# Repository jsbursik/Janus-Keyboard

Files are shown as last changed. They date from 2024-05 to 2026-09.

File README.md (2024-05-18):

# Janus Split Ergonomic Keyboard

## Janus

From [Wikipedia](https://en.wikipedia.org/wiki/Janus) on the god Janus: "In ancient Roman religion and myth, Janus (/ˈdʒeɪnəs/ JAY-nəs; Latin: Ianvs [ˈi̯aːnʊs]) is the god of beginnings, gates, transitions, time, duality, doorways, passages, frames, and endings. He is usually depicted as having two faces. The month of January is named for Janus (Ianuarius). According to ancient Roman farmers' almanacs, Juno was mistaken as the tutelary deity of the month of January, but Juno is the tutelary deity of the month of June."

## Motivation

I designed this keyboard after ordering and assembling a [Piantor](https://github.com/beekeeb/piantor) and not really liking the switches and keycaps. After realizing choc switches don't use the normal "+" stems I'm used to and seeing that the choc stems are a bit niche for finding keycaps - I started looking for other low-profile switch options that supported the more ubiquitous "+" stems.

Other issues involved key density, I didn't like how close together everything was. I stretched my fingers out, then closed them up and tried to get a shape that roughly followed the paths of my fingertips. I also added a few more keys than the Piantor has making this a 50 key (25 x 2) keyboard.

In comes the KS27 from Gateron. At one point I had owned a wireless keyboard that used the KS27 Linear Red switches and liked them for the most part, but these days I prefer a more tactile switch (break-over feel without the click). After finding some KS27 Browns on Amazon, I concluded they were what I was looking for. I found the hotswap sockets for the KS27 on Aliexpress and ordered a few hundred to be safe since shipping times were so long. Next I was on the hunt for blank keycaps and found that it was pretty easy to source some blank DSA profile caps from Amazon as well. I haven't used them on a full keyboard yet, but I believe it should be easier to feel out the different keys than the choc low-profile keycaps that came with the Piantor.

## Workflow

I used the web version of Ergogen [here](https://ergogen.cache.works) to get the general shape down until I was ready for all the footprinting and stuff that would have to happen locally. Once I was happy with the general shape, I went through the tedious task of editing footprints and converting them to the `.js` versions that Ergogen expects in the `footprints/` folder. I set up [npm-watch](https://www.npmjs.com/package/npm-watch) (`npm run watch`) to watch out for changes to the `config.yaml` file to automatically run Ergogen. Once everything was placed where I wanted it, I created a `kicad_project` folder separate from the output folder so any Ergogen runs down the road won't effect my work in Kicad (`npm run pcb-update` moves new PCB changes to the `kicad_project` folder). I then routed everything in KiCad version 8, making sure to weave the traces for the reversible nice!nano v2 footprint I made. After everything was routed and the DRC reported no errors, I exported the gerbers and sent them off to JLCPCB. The case was also generated using Ergogen as it's easy enough to do, still working on tweaking some clearances to make everything fit nicely.

## ZMK

This keyboard is meant to use the [nice!nano v2](https://nicekeyboards.com/nice-nano) with the [nice!view screen](https://nicekeyboards.com/nice-view) which means my firmware options were limited as this will be full wireless. The obvious choice feature-wise is ZMK. The documentation is a bit rough around the edges so I've had to do a decent amount of trial and error, as well as researching other ergo keyboard repos to see what they did. The firmware repo for this version of the Janus can be found [here](https://github.com/jsbursik/zmk-janus).

## Parts

| Part | Quantity |
| --- | --- |
| nice!nano v2 | 2 |
| sockets/pins for n!n v2 | 2 sets |
| nice!view | 2 |
| 5 pin header for nice!view, should come with it | 2 sets |
| 3.7v Lithium Battery | 2 |
| Gateron KS27 Hotswap Sockets | 50 |
| Gateron KS27 Low profile Switches | 50 |
| 1N4148 Diodes (SMD or Thru-hole) | 100 |
| M2 \* 4mm screws | 14 |
| M2 Threaded inserts 2 x 3 x 3.5mm | 14 |

Other than that, you just need the PCBs and keycaps of your choice.

Links to where I bought my parts:

- [nice!nano v2](https://typeractive.xyz/products/nice-nano)
- [nice!view](https://typeractive.xyz/products/nice-view)
- [sockets/pins](https://typeractive.xyz/products/machine-sockets-and-pins)
- [lithium batteries](https://typeractive.xyz/products/lithium-battery-110mah)
- [Gateron low-profile hot-swap socket](https://www.gateron.com/products/gateron-low-profile-switch-hot-swap-pcb-socket?VariantsId=10234)
- [Gateron KS27 brown switched](https://www.amazon.com/Gateron-ks-27-Switches-Mechanical-Keyboards/dp/B09WYGKDVN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)
- [1N4148WS Surface Mount Diodes x100](https://www.amazon.com/dp/B089KD46P6?psc=1&ref=ppx_yo2ov_dt_b_product_details)
- [M2 screws](https://www.amazon.com/dp/B0BX96SMW4?psc=1&ref=ppx_yo2ov_dt_b_product_details)
- [M2 threaded inserts](https://www.amazon.com/dp/B0B8GN63S2?psc=1&ref=ppx_yo2ov_dt_b_product_details)

## Keymap Layout

This is still very much a work in progress. I've been using the [keymap editor found here](https://nickcoutsos.github.io/keymap-editor/) to try and come up with a barebones setup.

** TODO: add images

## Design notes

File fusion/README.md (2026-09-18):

# Fusion case script

`JanusCase` rebuilds the ergogen case as a native Fusion design instead of an STL:
real sketches (lines, arcs, circles) and extrudes, with every height as a user parameter.

## Use

1. Run `npm run build` so `output/outlines` contains the ergogen outline DXFs (including the `_`-prefixed debug ones).
2. In Fusion: **Utilities → Add-Ins → Scripts and Add-Ins**, click **+** next to *My Scripts*, choose *Script or add-in from device*, and pick the `fusion/JanusCase` folder.
3. Select **JanusCase** and click **Run**. It opens a new design with:
   - **Case left**: floor + wall − slider cutout + insert standoffs + PCB supports, as in the `case` recipe in `config.yaml`
   - **Case right**: a mirror of the left half
   - **PCB outline** sketch at the height the PCB sits, and a hidden **Keycaps** sketch
4. Change heights under **Modify → Change Parameters** (`floor_thickness`, `wall_height`, `standoff_height`, ...).

Outline shapes (wall thickness, clearance, insert positions) still come from `config.yaml`.
Change them there, rebuild, and run the script again.

The script expects Fusion's default **Z up** orientation. With Y up, the case is built standing on its edge.

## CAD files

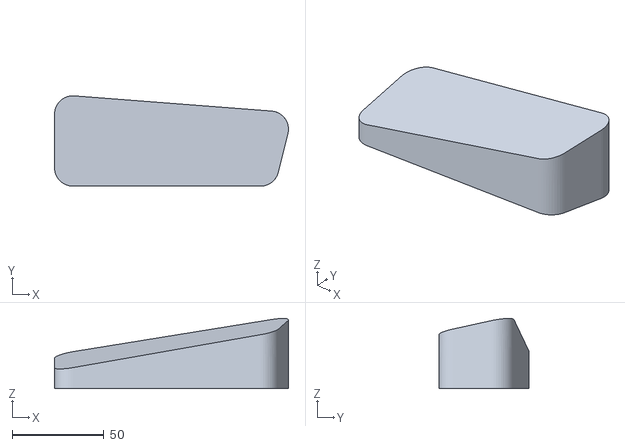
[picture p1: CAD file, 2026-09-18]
output/cases/Split Keyboard Support LH.stl
127.4 x 49.2 x 38.2

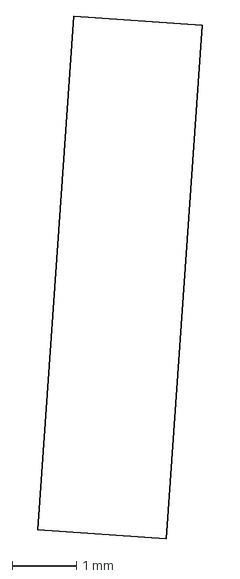
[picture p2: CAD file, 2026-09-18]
output/outlines/_slider_hole.dxf
2.55 x 8.12 mm

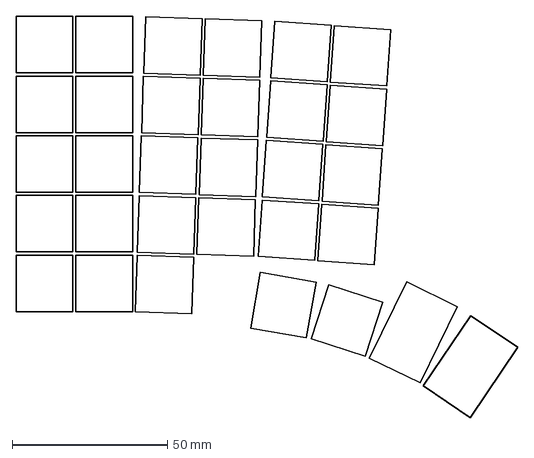
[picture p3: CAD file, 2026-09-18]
output/points/demo.dxf
161.4 x 129.1 mm

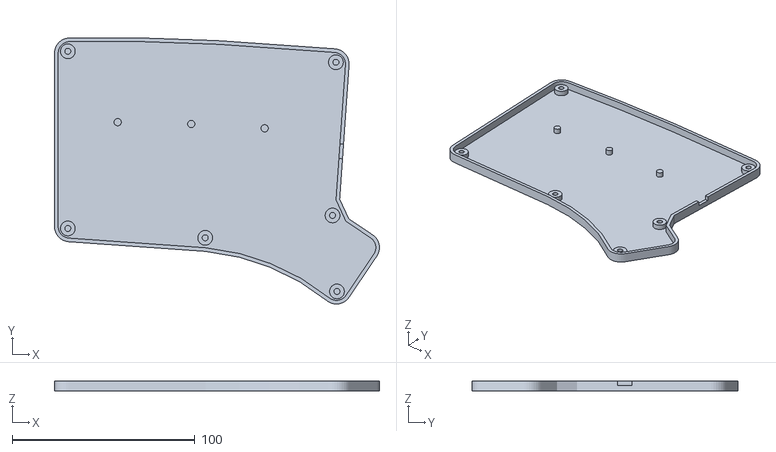
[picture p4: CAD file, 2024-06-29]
output/cases/case.stl
178.0 x 145.7 x 5.60

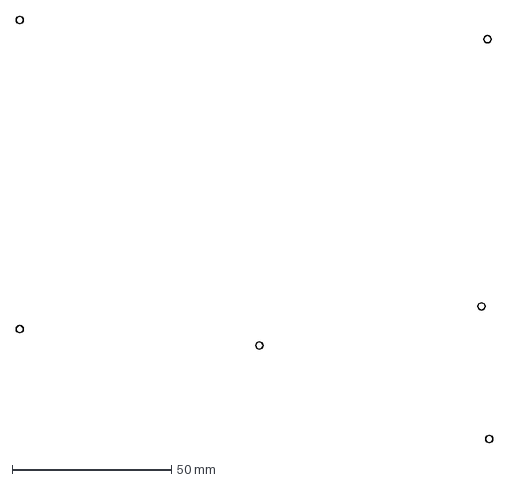
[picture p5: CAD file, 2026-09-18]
output/outlines/_board_holes.dxf
149.7 x 133.8 mm

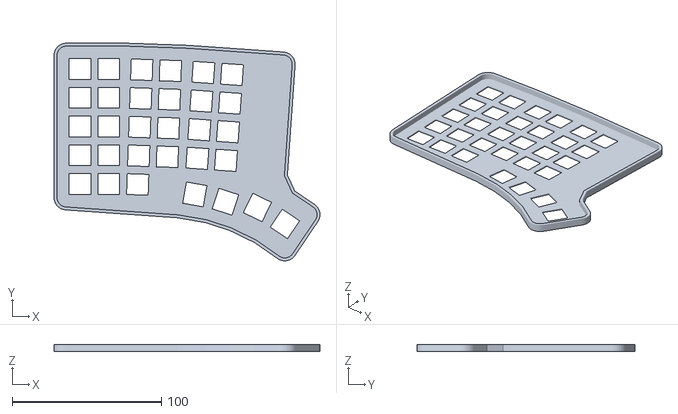
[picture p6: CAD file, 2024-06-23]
output/cases/key_tester.stl
178.0 x 145.7 x 5.00

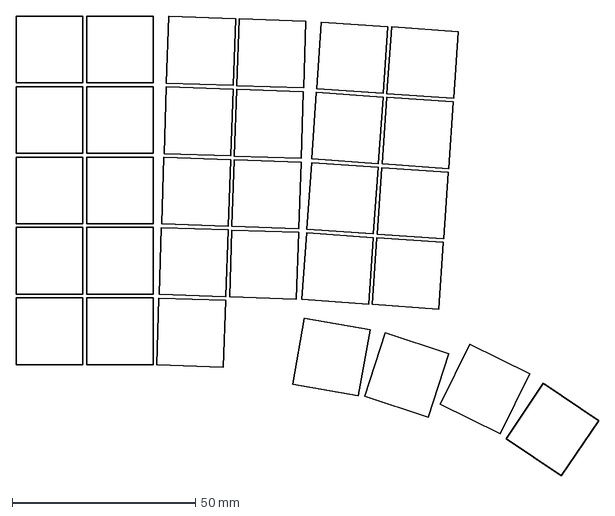
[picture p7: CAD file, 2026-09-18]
output/outlines/keycaps.dxf
158.8 x 125.3 mm

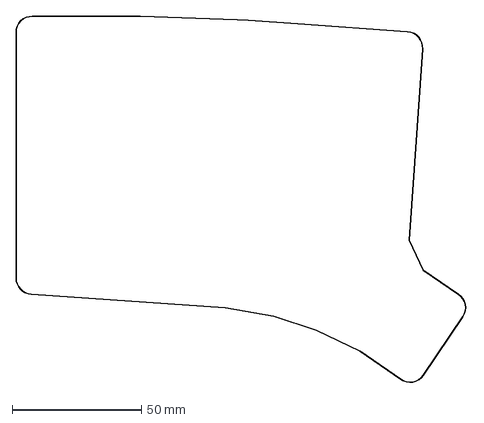
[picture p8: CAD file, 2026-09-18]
output/outlines/_board_case_clearance.dxf
174.8 x 141.9 mm

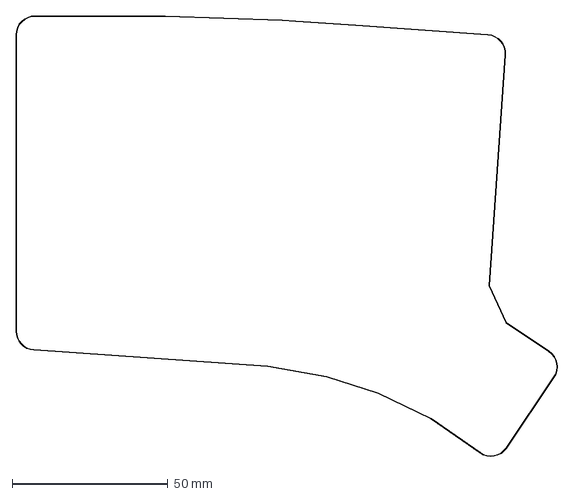
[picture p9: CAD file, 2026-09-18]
output/outlines/board.dxf
174.2 x 141.3 mm

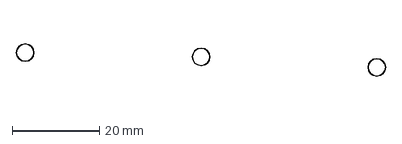
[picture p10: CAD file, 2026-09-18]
output/outlines/_board_supports.dxf
84.5 x 7.36 mm

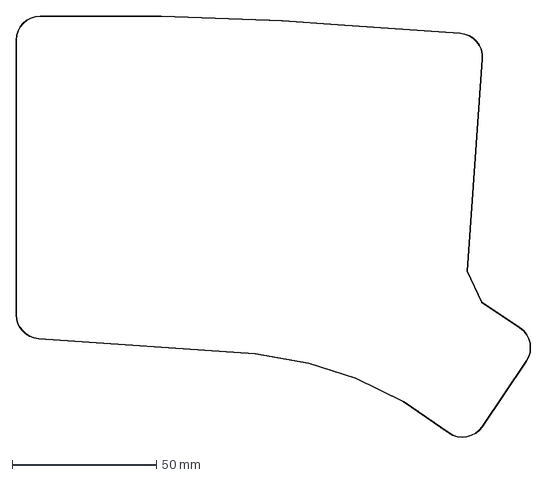
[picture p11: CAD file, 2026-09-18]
output/outlines/_board_xl.dxf
179.1 x 146.0 mm

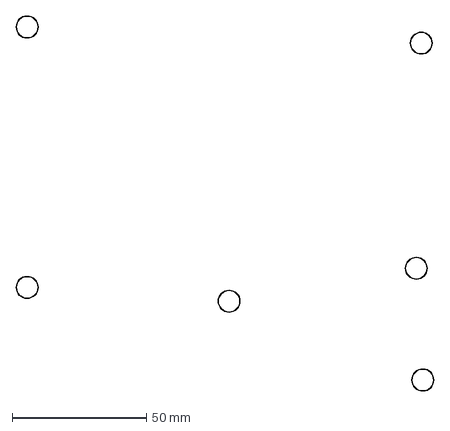
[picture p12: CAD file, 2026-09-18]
output/outlines/_insert_walls.dxf
155.5 x 139.6 mm

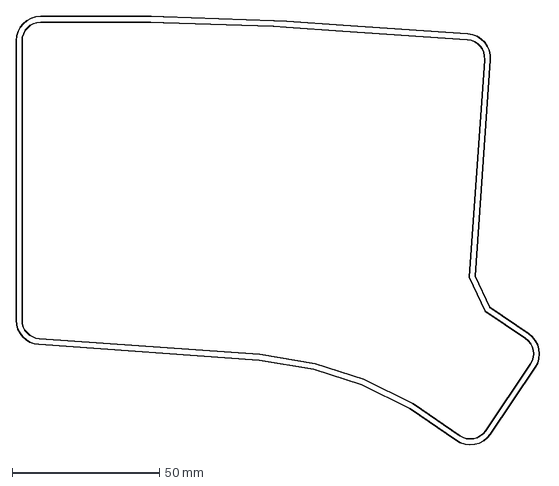
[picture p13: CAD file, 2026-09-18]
output/outlines/wall.dxf
179.1 x 146.0 mm

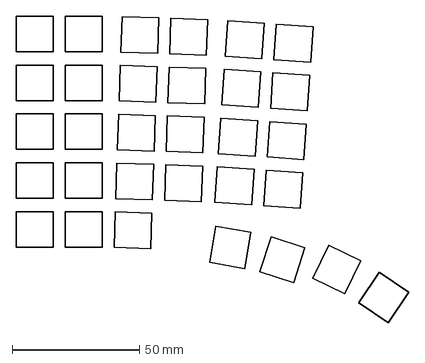
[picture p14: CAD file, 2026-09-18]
output/outlines/switches.dxf
154.1 x 120.5 mm

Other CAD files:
output/outlines/_insert_holes.dxf
output/outlines/inserts.dxf
output/outlines/keyplate.dxf
output/outlines/drilled_board.dxf
output/outlines/board_xl.dxf
output/outlines/combo.dxf
output/outlines/holes.dxf
output/outlines/keyplate_drilled.dxf
output/outlines/standoffs.dxf

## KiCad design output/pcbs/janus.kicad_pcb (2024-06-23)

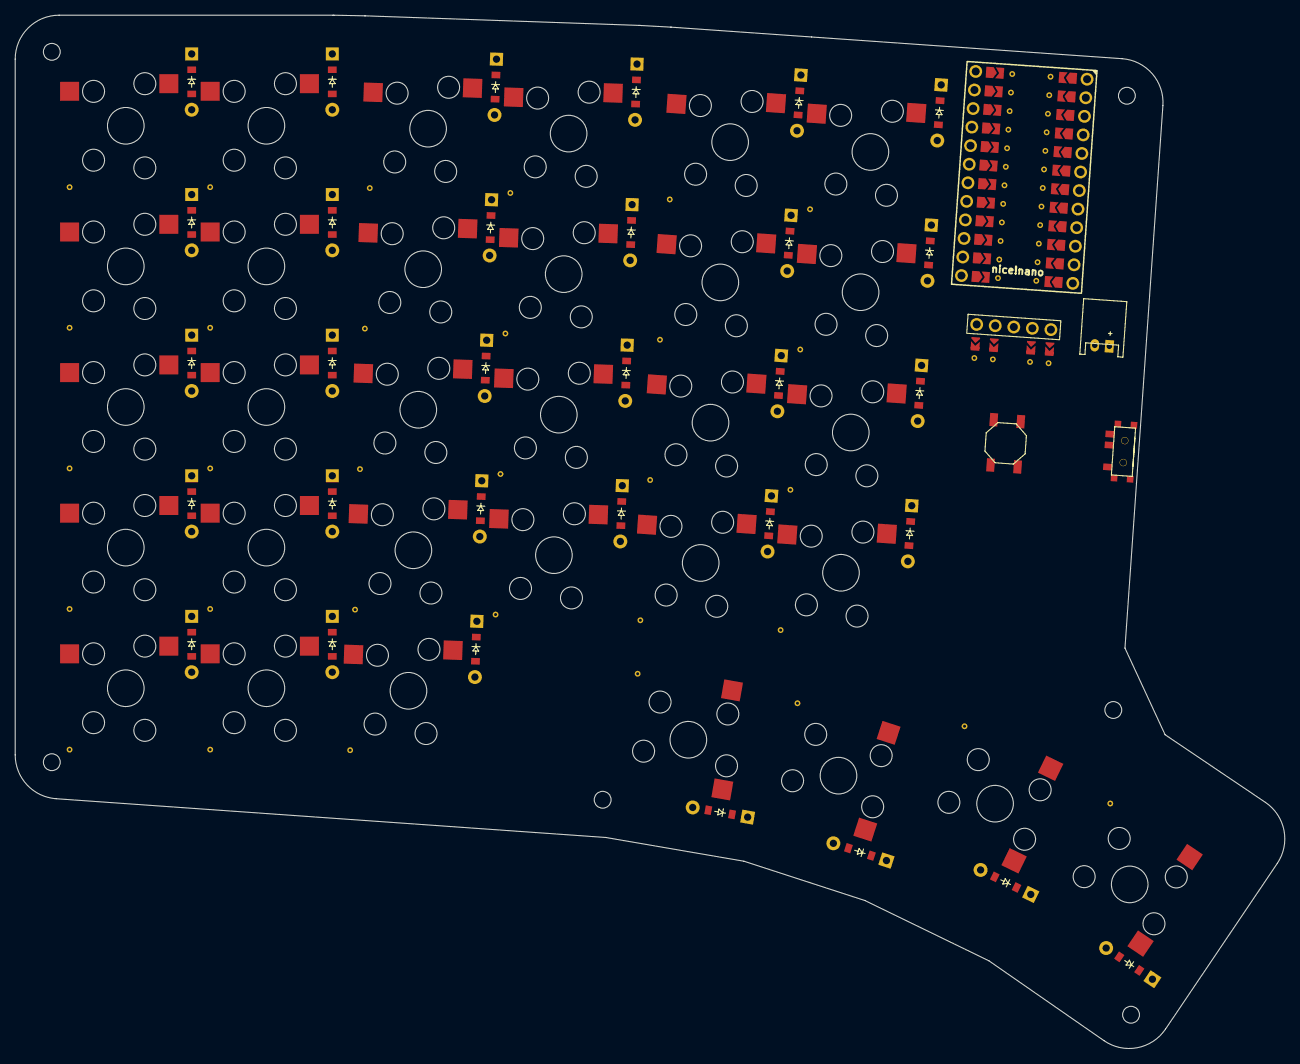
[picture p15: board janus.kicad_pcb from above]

Board: 2 copper layers, 173.4 x 141.1 mm, 67 parts (0 on the bottom side), 48 nets, no tracks yet.

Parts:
B1: SW_TACT_ALPS_SKQGABE010
D1, D2, D3, D4, D5, D6, D7, D8, D9, D10, D11, D12, D13, D14, D15, D16, D17, D18, D19, D20, D21, D22, D23, D24, D25, D26, D27, D28, D29, D30, D31: ComboDiode
JST1: JST_PH_S2B-PH-K_02x2.00mm_Angled
MCU1: nice!nano_v2
OLED1: nice!view; niceview
S1, S2, S3, S4, S5, S6, S7, S8, S9, S10, S11, S12, S13, S14, S15, S16, S17, S18, S19, S20, S21, S22, S23, S24, S25, S26, S27, S28, S29, S30, S31: ks27; gateron-ks27
T1: SPDT_C128955

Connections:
BPOS: JST1.1, T1.1
GND: B1.1, JST1.2, MCU1.GND
P5: D5.1, D10.1, D15.1, D19.1, D23.1, D27.1, MCU1.P5
P6: D4.1, D9.1, D14.1, D18.1, D22.1, D26.1, MCU1.P6
P7: D3.1, D8.1, D13.1, D17.1, D21.1, D25.1, MCU1.P7
P8: D2.1, D7.1, D12.1, D16.1, D20.1, D24.1, MCU1.P8
P9: D1.1, D6.1, D11.1, D28.1, D29.1, D30.1, D31.1, MCU1.P9
P10: MCU1.P10, S16.1, S17.1, S18.1, S19.1, S28.1
P14: MCU1.P14, S6.1, S7.1, S8.1, S9.1, S10.1
P15: MCU1.P15, S1.1, S2.1, S3.1, S4.1, S5.1
P16: MCU1.P16, S11.1, S12.1, S13.1, S14.1, S15.1
P18: MCU1.P18, S31.1
P19: MCU1.P19, S20.1, S21.1, S22.1, S23.1, S29.1
P20: MCU1.P20, S24.1, S25.1, S26.1, S27.1, S30.1
RAW: MCU1.B+, T1.2
RST: B1.2, MCU1.RST
VCC: MCU1.VCC, OLED1.3
home_cluster: D30.2, S30.2
index_bottom: D20.2, S20.2
index_home: D21.2, S21.2
index_number: D23.2, S23.2
index_top: D22.2, S22.2
inner_bottom: D24.2, S24.2
inner_cluster: D29.2, S29.2
inner_home: D25.2, S25.2
inner_number: D27.2, S27.2
inner_top: D26.2, S26.2
middle_bottom: D16.2, S16.2
middle_home: D17.2, S17.2
middle_number: D19.2, S19.2
middle_top: D18.2, S18.2
mod_cluster: D28.2, S28.2
outer_bottom: D2.2, S2.2
outer_cluster: D31.2, S31.2
outer_home: D3.2, S3.2
outer_mod: D1.2, S1.2
outer_number: D5.2, S5.2
outer_top: D4.2, S4.2
pinky_bottom: D7.2, S7.2
pinky_home: D8.2, S8.2
pinky_mod: D6.2, S6.2
pinky_number: D10.2, S10.2
pinky_top: D9.2, S9.2
ring_bottom: D12.2, S12.2
ring_home: D13.2, S13.2
ring_mod: D11.2, S11.2
ring_number: D15.2, S15.2
ring_top: D14.2, S14.2

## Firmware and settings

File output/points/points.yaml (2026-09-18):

matrix_outer_mod:
    x: 50
    'y': -150
    r: 0
    meta:
        stagger: 0
        spread: 19.2
        splay: 0
        origin:
            - 0
            - 0
        orient: 0
        shift:
            - 0
            - 0
        rotate: 0
        adjust: {}
        width: 18.2
        height: 18.2
        padding: 19.2
        autobind: 10
        skip: false
        asym: both
        colrow: outer_mod
        name: matrix_outer_mod
        column_net: P15
        row_net: P9
        zone:
            columns:
                outer:
                    key:
                        column_net: P15
                    rows: {}
                    name: outer
                pinky:
                    key:
                        column_net: P14
                    rows: {}
                    name: pinky
                ring:
                    key:
                        splay: -2
                        spread: kp + 0.2
                        stagger: -0.35
                        column_net: P16
                    rows: {}
                    name: ring
                middle:
                    rows:
                        mod:
                            skip: true
                    key:
                        column_net: P10
                    name: middle
                index:
                    key:
                        splay: -2
                        spread: kp + 0.2
                        stagger: -0.35
                        column_net: P19
                    rows:
                        mod:
                            skip: true
                    name: index
                inner:
                    rows:
                        mod:
                            skip: true
                    key:
                        column_net: P20
                    name: inner
            rows:
                mod:
                    row_net: P9
                bottom:
                    row_net: P8
                home:
                    row_net: P7
                top:
                    row_net: P6
                number:
                    row_net: P5
            name: matrix
        col:
            key:
                column_net: P15
            rows: {}
            name: outer
        row: mod
        bind:
            - 10
            - 10
            - 0
            - 0
matrix_outer_bottom:
    x: 50
    'y': -130.8
    r: 0
    meta:
        stagger: 0
        spread: 19.2
        splay: 0
        origin:
            - 0
            - 0
        orient: 0
        shift:
            - 0
            - 0
        rotate: 0
        adjust: {}
        width: 18.2
        height: 18.2
        padding: 19.2
        autobind: 10
        skip: false
        asym: both
        colrow: outer_bottom
        name: matrix_outer_bottom
        column_net: P15
        row_net: P8
        zone:
            columns:
                outer:
                    key:
                        column_net: P15
                    rows: {}
                    name: outer
                pinky:
                    key:
                        column_net: P14
                    rows: {}
                    name: pinky
                ring:
                    key:
                        splay: -2
                        spread: kp + 0.2
                        stagger: -0.35
                        column_net: P16
                    rows: {}
                    name: ring
                middle:
                    rows:
                        mod:
                            skip: true
                    key:
                        column_net: P10
                    name: middle
                index:
                    key:
                        splay: -2
                        spread: kp + 0.2
                        stagger: -0.35
                        column_net: P19
                    rows:
                        mod:
                            skip: true
                    name: index
                inner:
                    rows:
                        mod:
                            skip: true
                    key:
                        column_net: P20
                    name: inner
            rows:
                mod:
                    row_net: P9
                bottom:
                    row_net: P8
                home:
                    row_net: P7
                top:
                    row_net: P6
                number:
                    row_net: P5
            name: matrix
        col:
            key:
                column_net: P15
            rows: {}
            name: outer
        row: bottom
        bind:
            - 10
            - 10
            - 10
            - 0
matrix_outer_home:
    x: 50
    'y': -111.60000000000001
    r: 0
    meta:
        stagger: 0
        spread: 19.2
        splay: 0
        origin:
            - 0
            - 0
        orient: 0
        shift:
            - 0
            - 0
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

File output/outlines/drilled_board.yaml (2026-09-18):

models:
    export:
        models:
            a:
                models:
                    a:
                        models: {}
                        origin:
                            - 0
                            - 0
                    b:
                        models:
                            '0':
                                paths:
                                    p1_Top:
                                        type: line
                                        origin:
                                            - 34.9
                                            - -159.1
                                        end:
                                            - 34.9
                                            - -64.1
                                    p1_EndCap:
                                        type: arc
                                        origin:
                                            - 40.9
                                            - -64.1
                                        radius: 6
                                        startAngle: 90
                                        endAngle: 180
                                    p2_Top:
                                        type: line
                                        origin:
                                            - 40.9
                                            - -58.10000000000001
                                        end:
                                            - 78.3
                                            - -58.10000000000001
                                    p4_EndCap:
                                        type: arc
                                        origin:
                                            - 78.3
                                            - -64.10000000000001
                                        radius: 6
                                        startAngle: 448.8450499018668
                                        endAngle: 90
                                    p5_Top:
                                        type: line
                                        origin:
                                            - 78.4209379
                                            - -58.10121900000001
                                        end:
                                            - 82.624348
                                            - -58.185961500000005
                                    p5_EndCap:
                                        type: arc
                                        origin:
                                            - 82.5034101
                                            - -64.18474250000001
                                        radius: 6
                                        startAngle: 447.999999823808
                                        endAngle: 88.8450496552912
                                    p6_Top:
                                        type: line
                                        origin:
                                            - 82.71280710000002
                                            - -58.188397500000015
                                        end:
                                            - 120.09002400000001
                                            - -59.493638600000004
                                    p8_EndCap:
                                        type: arc
                                        origin:
                                            - 119.88062700000002
                                            - -65.4899836
                                        radius: 6
                                        startAngle: 446.8450496094199
                                        endAngle: 88.0000001201171
                                    p9_Top:
                                        type: line
                                        origin:
                                            - 120.21084570000002
                                            - -59.49907750000001
                                        end:
                                            - 124.40873810000002
                                            - -59.73046530000002
                                    p9_EndCap:
                                        type: arc
                                        origin:
                                            - 124.07851940000002
                                            - -65.72137140000001
                                        radius: 6
                                        startAngle: 445.9999994508794
                                        endAngle: 86.8450495834867
                                    p10_Top:
                                        type: line
                                        origin:
                                            - 124.49705829999995
                                            - -59.73598710000001
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

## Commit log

2024-05-13 just the starting template
    [demo.dxf]
2024-05-13 making sure the footprints folder exists for the future
2024-05-14 started footprinting and hooking up nets
2024-05-14 added fancy mounting hole from tutorial
2024-05-14 generated files
    [board.dxf, keycaps.dxf, switches.dxf]
2024-05-15 reversible button fp, original from ergogen
2024-05-15 added watch and pcb-update scripts
2024-05-15 everything placed, sizing tweaked, holes made. Just need a case.
2024-05-15 corrected screw size, added another mount hole
    [config.yaml]
2024-05-15 Gerber files for manufacture
    [janus-B_Cu.gbr, janus-B_Mask.gbr, janus-B_Paste.gbr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]
2024-05-15 routed and completed
    [janus.kicad_pcb]
2024-05-15 generated output
    [drilled_board.dxf, holes.dxf, janus.kicad_pcb]
2024-05-15 removing kicad pcb lock file
2024-05-17 working on case
2024-05-17 adjusting radii, fixed comments
    [config.yaml]
2024-05-17 fixed holes in PCB manually, generated new gerbers
    [janus-B_Cu.gbr, janus-B_Mask.gbr, janus-B_Paste.gbr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]
2024-05-21 thicker standoffs, clearance stuff, power slider cutout
    [config.yaml]
2024-06-14 setup basic layout, made key tester, need to print
2024-06-17 supports, adjustments to pcb, good to wire?
2024-06-23 final routing and generated gerbers
    [janus-B_Cu.gbr, janus-B_Mask.gbr, janus-B_Paste.gbr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]
2024-06-29 removed keytester stuff, fixed some outlines, finished the case
    [config.yaml]
2026-09-18 working on redesigning case
    [Split Keyboard Support LH.stl, _board_case_clearance.dxf, _board_holes.dxf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]
